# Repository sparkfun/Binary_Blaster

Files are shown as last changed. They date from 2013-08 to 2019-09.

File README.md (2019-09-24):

Binary Blaster Kit
==============

Binary Blaster (https://www.sparkfun.com/products/12037)

[Binary Blaster (KIT-12037)](https://www.sparkfun.com/products/12037)

This beginner's thru-hole soldering kit is a fun way to learn binary conversion. It displays a decimal value, 
and you are challenged to press the buttons to represent the correct binary version. Correctly press all 15 
values and you win!

Repository Contents
-------------------

* **/Firmware** - Firmware that comes programmed on the kit.
* **/Hardware** - All Eagle design files (.brd, .sch)

Documentation
-------------------
* [Assembly Guide](https://learn.sparkfun.com/tutorials/binary-blaster-assembly-guide)

License Information
-------------------
The hardware is released under [Creative Commons ShareAlike 4.0 International](https://creativecommons.org/licenses/by-sa/4.0/).
The code is beerware; if you see me (or any other SparkFun employee) at the local, and you've found our code helpful, please buy us a round!

Distributed as-is; no warranty is given.

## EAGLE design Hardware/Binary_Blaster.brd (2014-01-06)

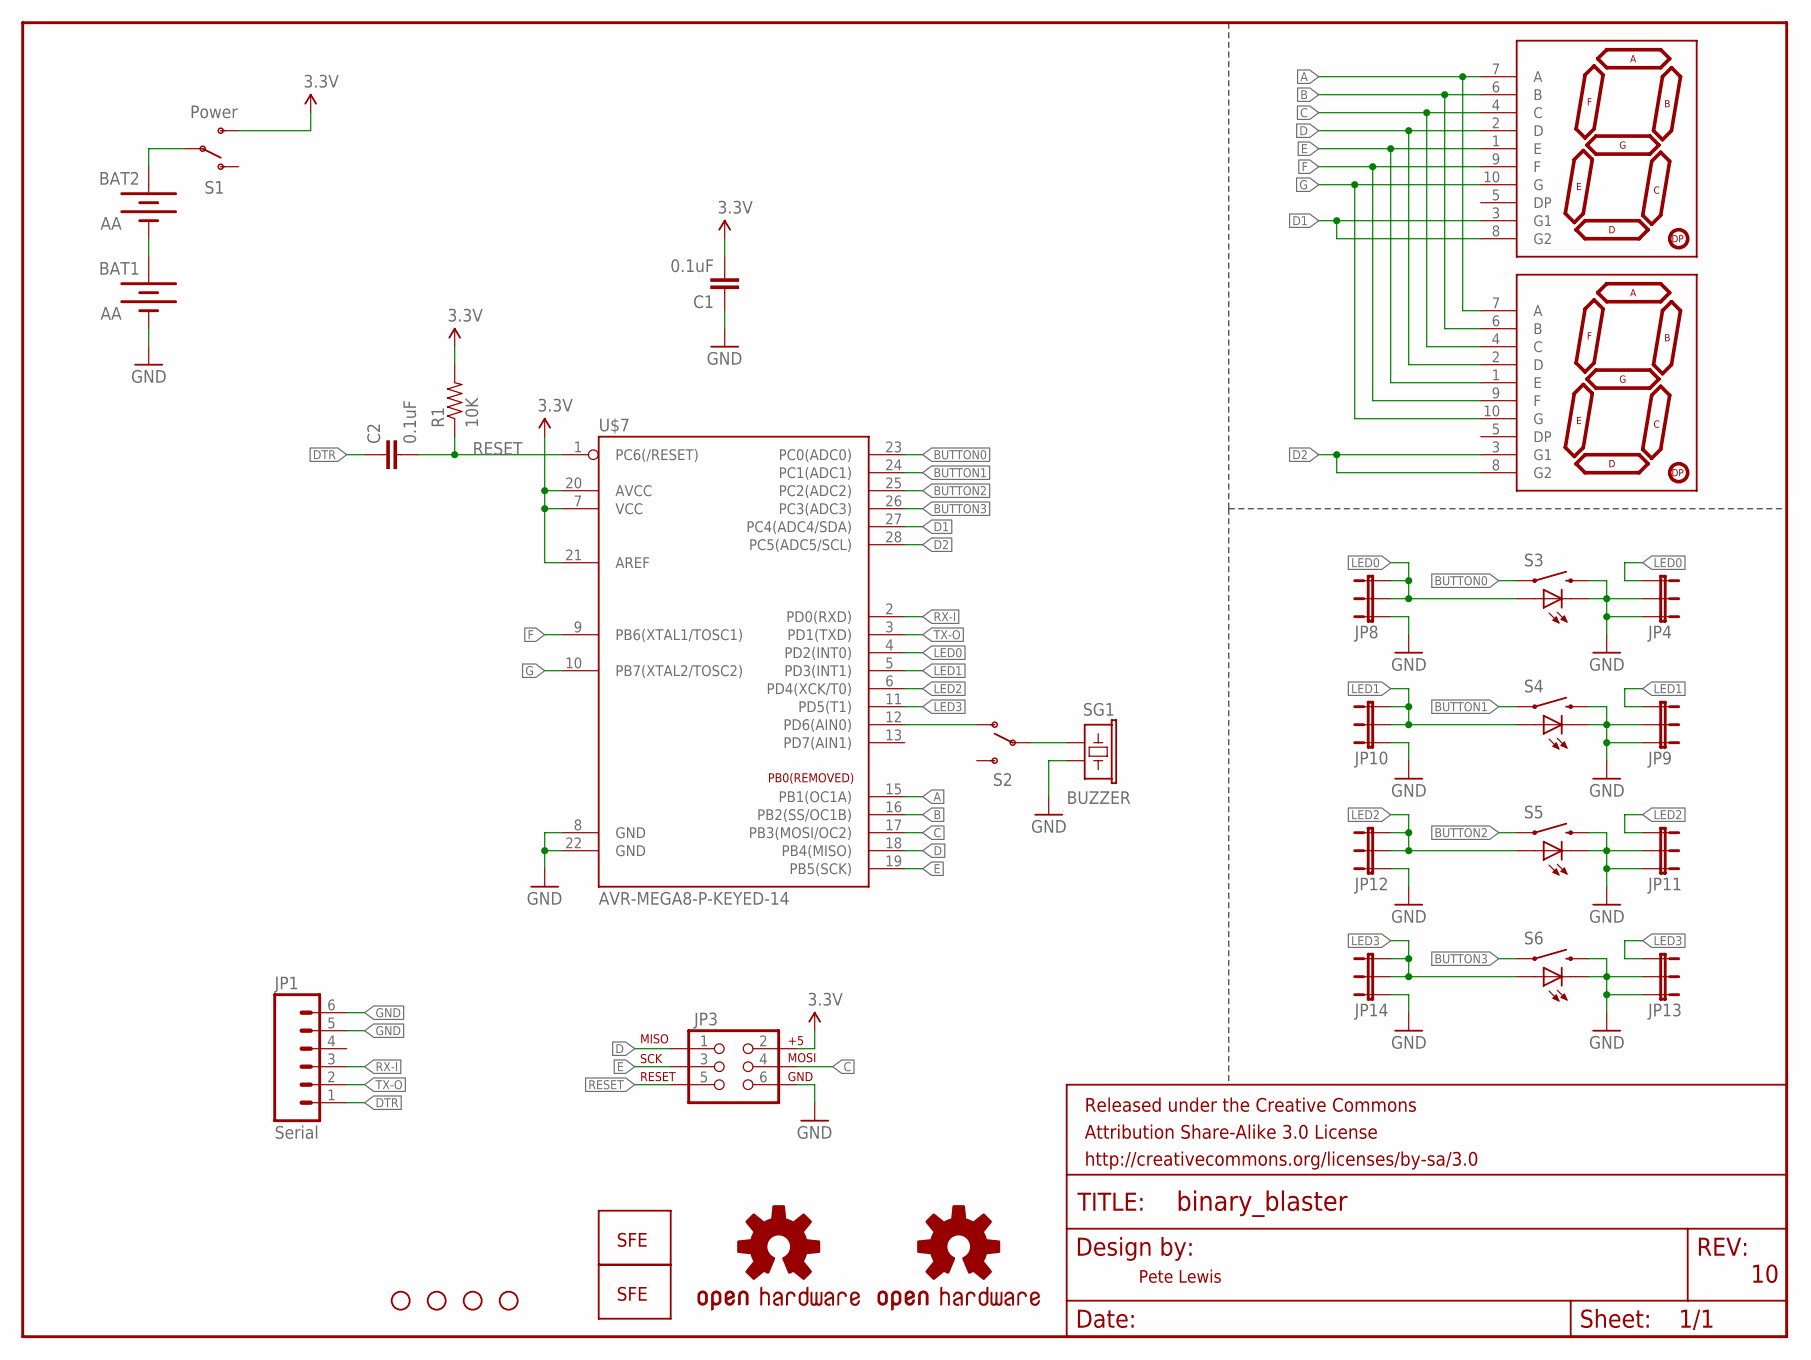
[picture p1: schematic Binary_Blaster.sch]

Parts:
BAT1, BAT2: AA; BATTERY-AA-KIT
C1, C2: 0.1uF; CAP-PTH-SMALL-KIT
FRAME1: FRAME-LETTER; CREATIVE_COMMONS
JP1: Serial; 1X06-NOSILK
JP2, JP5, JP6, JP7: STAND-OFF
JP3: AVR_SPI_PRG_6NS; 2X3-NS
JP4, JP8, JP9, JP10, JP11, JP12, JP13, JP14: JUMPER-3SMD; SJ_3
LOGO1, LOGO2: LOGO-SFENEW; SFE-NEW-WEBLOGO
R1: 10K; AXIAL-0.3-KIT
S1: Power; SWITCH-SPDT_KIT
S2: SWITCH-SPDTKIT; SWITCH-SPDT_KIT
S3, S4, S5, S6: SWITCH-MOMENTARY-LEDEZ; TACTILE-PTH-LED-12MM-EZ
SG1: BUZZER; BUZZER-12MM-KIT
U$1, U$6: 7-SEGMENT-DISPLAY-1"-REDEZ; 7-SEGMENT-1"PTH-EZ
U$2: OSHW-LOGOL; OSHW-LOGO-L
U$3: OSHW-LOGOS; OSHW-LOGO-S
U$7: AVR-MEGA8-P-KEYED-14; DIL28-3_KEYED-14

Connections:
3.3V: C1.2, JP3.2, R1.P$2 (2), S1.3 (S), U$7.7 (VCC), U$7.20 (AVCC), U$7.21 (AREF)
A: U$1.7 (A), U$6.7 (A), U$7.15 (PB1(OC1A))
B: U$1.6 (B), U$6.6 (B), U$7.16 (PB2(SS/OC1B))
BUTTON0: S3.4 (1), U$7.23 (PC0(ADC0))
BUTTON1: S4.4 (1), U$7.24 (PC1(ADC1))
BUTTON2: S5.4 (1), U$7.25 (PC2(ADC2))
BUTTON3: S6.4 (1), U$7.26 (PC3(ADC3))
C: JP3.4, U$1.4 (C), U$6.4 (C), U$7.17 (PB3(MOSI/OC2))
D: JP3.1, U$1.2 (D), U$6.2 (D), U$7.18 (PB4(MISO))
D1: U$1.3 (G1), U$1.8 (G2), U$7.27 (PC4(ADC4/SDA))
D2: U$6.3 (G1), U$6.8 (G2), U$7.28 (PC5(ADC5/SCL))
DTR: C2.1, JP1.1
E: JP3.3, U$1.1 (E), U$6.1 (E), U$7.19 (PB5(SCK))
F: U$1.9 (F), U$6.9 (F), U$7.9 (PB6(XTAL1/TOSC1))
G: U$1.10 (G), U$6.10 (G), U$7.10 (PB7(XTAL2/TOSC2))
GND: BAT1.GND@1 (-), C1.1, JP1.5, JP1.6, JP3.6, JP4.2, JP4.3, JP8.1, JP9.2, JP9.3, JP10.1, JP11.2, JP11.3, JP12.1, JP13.2, JP13.3, JP14.1, S3.2, S3.C, S4.2, S4.C, S5.2, S5.C, S6.2, S6.C, SG1.- (2), U$7.8 (GND), U$7.22 (GND)
LED0: JP4.1, JP8.2, JP8.3, S3.A, U$7.4 (PD2(INT0))
LED1: JP9.1, JP10.2, JP10.3, S4.A, U$7.5 (PD3(INT1))
LED2: JP11.1, JP12.2, JP12.3, S5.A, U$7.6 (PD4(XCK/T0))
LED3: JP13.1, JP14.2, JP14.3, S6.A, U$7.11 (PD5(T1))
unnamed: S2.2, SG1.+ (1)
unnamed: BAT2.PWR@1 (+), S1.2
unnamed: S2.1 (O), U$7.12 (PD6(AIN0))
unnamed: BAT1.PWR@1 (+), BAT2.GND@1 (-)
RESET: C2.2, JP3.5, R1.P$1 (1), U$7.1 (PC6(/RESET))
RX-I: JP1.3, U$7.2 (PD0(RXD))
TX-O: JP1.2, U$7.3 (PD1(TXD))

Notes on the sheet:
Pete Lewis

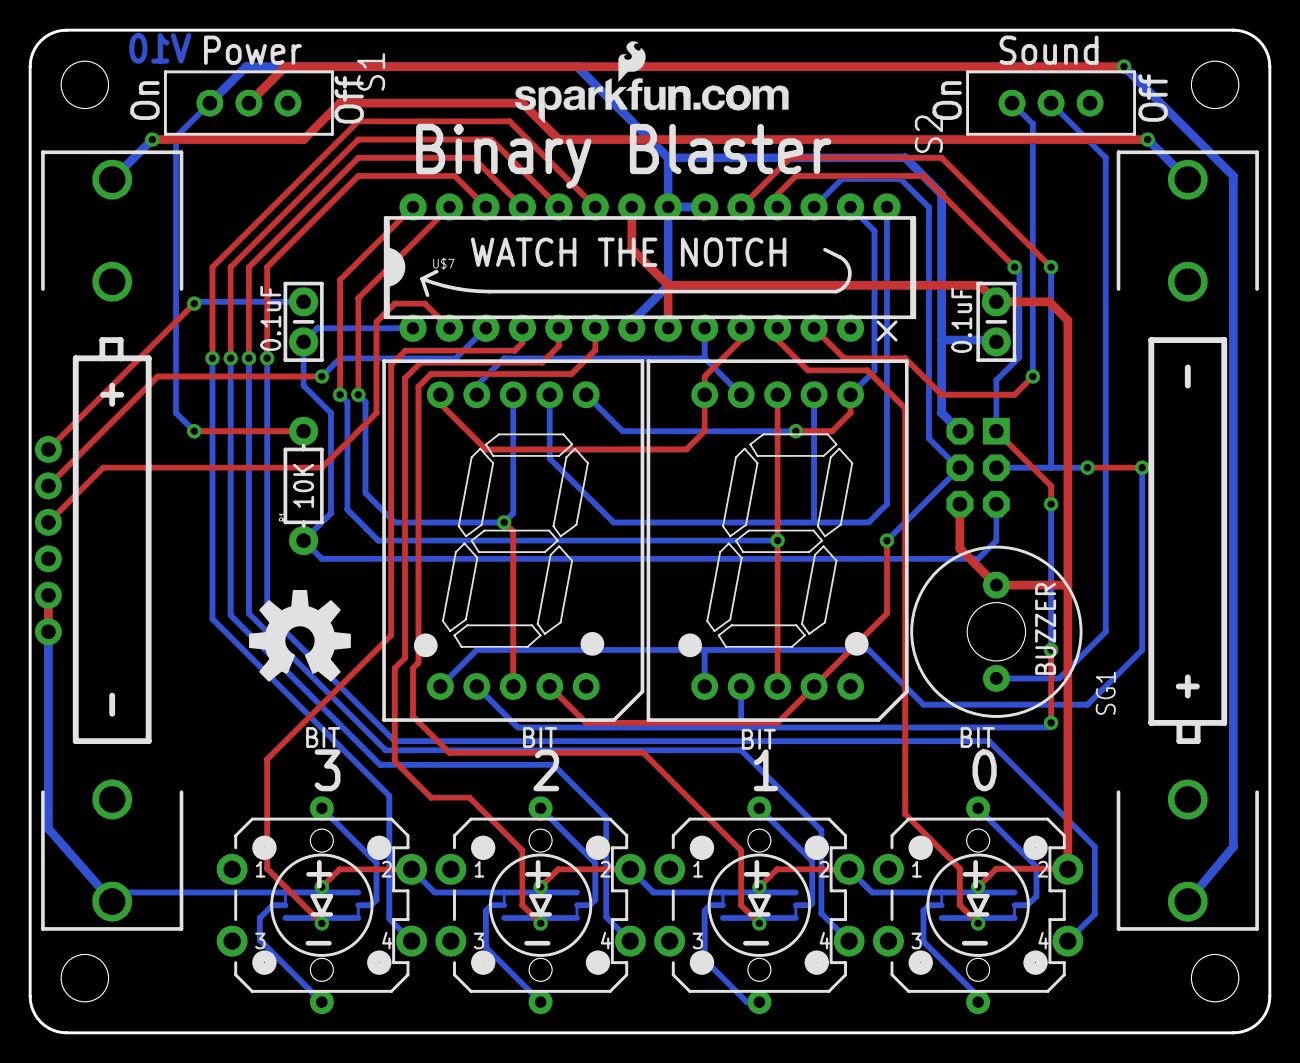
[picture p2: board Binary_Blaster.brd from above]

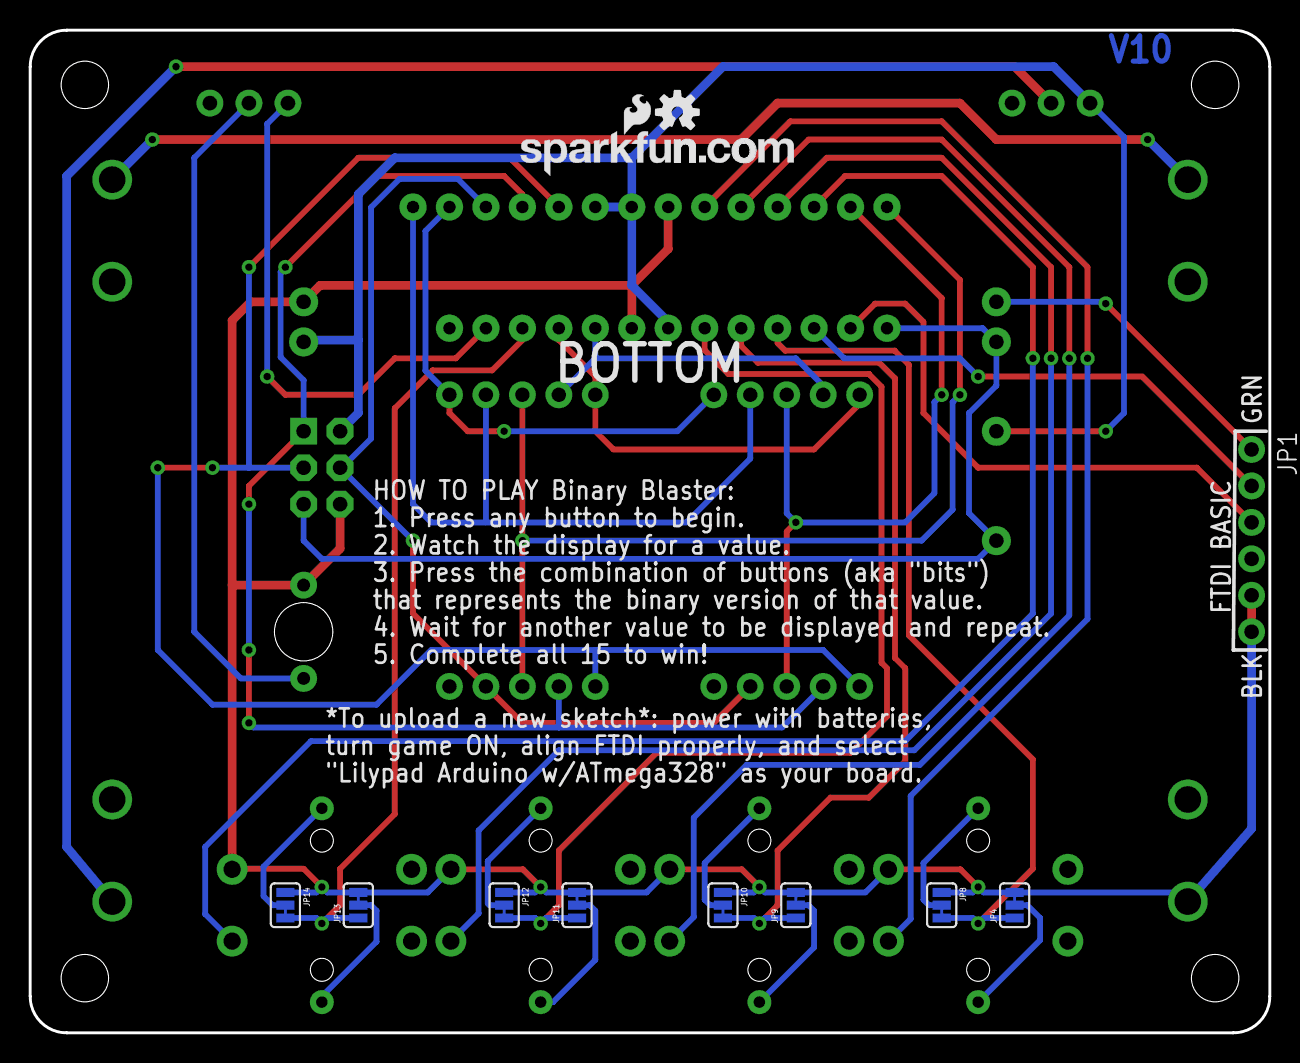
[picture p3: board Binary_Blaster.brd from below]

Board: 2 copper layers, 86.4 x 69.8 mm, 34 parts (12 on the bottom side), 27 nets.

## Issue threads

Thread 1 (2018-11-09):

PCB does not show polarity of buzzer

ursminor, 2018-11-09:

bboyho, 2019-09-24:
Hi,

Thank you for the feedback. I just saw your issue. The buzzer has a polarity marker but it should not matter when soldered on the board. The buzzer will still function regardless of the orientation. Checking with the engineer, we do not believe that this is a significant issue to warrant a revision. If you would like to follow along with the [assembly guide](https://learn.sparkfun.com/tutorials/binary-blaster-assembly-guide#buzzer-and-switches) feel free to insert the buzzer into the PCB by having the "+" close to the "BIT 0" silkscreen as indicated in the image.

If you happen to solder the buzzer differently but wanted to follow the guide, you can rework the board by heating both through holes with your soldering iron and carefully remove the component from the through hole. Using a solder sucker or the [slap method](https://www.sparkfun.com/tutorials/339), remove any remaining solder on the PTH pads. After removing any excess solder from the pins, insert buzzer back into through holes with the orientation based on the guide before soldering the pins again. When reworking PTH components, there is a risk of pulling pads so make sure to fully heat the solder joints!

Closed 2019-09-24.

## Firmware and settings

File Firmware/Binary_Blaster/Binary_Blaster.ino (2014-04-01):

/******************************************************************************
Binary_Blaster.ino
Firmware for the Binary Blaster PTH Soldering Kit
Pete Lewis @ SparkFun Electronics
February 13th 2014
https://github.com/sparkfun/Binary_Blaster

This code is meant to be used with SFE's Binary Blaster thru-hole soldering kit. 
It can be found here: https://www.sparkfun.com/products/12037
It is an educational kit that is meant to teach thru-hole soldering, 
and also challenge the player to practice binary conversion. The default playing
mode is to display the values in decimal. If you'd like to play hexadecimal 
mode, then you can do so by holding down the "bit0" button while powering up.

Resources:
No additional library requirements

Development environment specifics:
Arduino 1.0.5
Hardware: v10*
*Note, PB0 (aka arduino pin "D8") has been removed from the IC, to make it a
keyed part. This helps beginners avoid incorrect placement of the IC.

This code is beerware; if you see me (or any other SparkFun employee) at the
local, and you've found our code helpful, please buy us a round!

Distributed as-is; no warranty is given.
******************************************************************************/

//-----------------------------------------------------------------------------
// HARDWARE PIN DECLARATIONS

// Define the anode (aka "+" or "high side") pins on the 7-segment displays
  // There are two 7-segment displays on this game.
  // We control each display by both writing the anode digit pin HIGH,
  // and writing the desired single segment cathode pin LOW. Only one segment 
  // may be actually lit at one instance. We blink segments in a fast 
  // sequence, and then it appears to illuminate multiple segments 
  // simultaneously. 
  // ***Note, the cathodes for the 7 segments are all connected
  // to the pins on PORTB. These are controlled by writing directly to the
  // entire port (e. g. "PORTB = ~0b00001100;") in function set_7segment_pins().
const int digit_1_anode = A5;
const int digit_2_anode = A4;

// Define pins connected to the switches inside the tactile LED buttons
  // Note, the tactile buttons have switches and LEDs inside them.
  // These pin definitions are for the switches. They will be set as inputs,
  // and used to know if the player is pressing the button down.
  // Each button corresponds to a bit, and therefore has the "bit0" or
  // "bit1" in it's name. This helps keep the player's input more
  // understandable. This pins are read in the function, read_buttons().
const int button_input_pin_bit0 = A3;
const int button_input_pin_bit1 = A2;
const int button_input_pin_bit2 = A1;
const int button_input_pin_bit3 = A0;

// Define pins connected to the LEDs inside the tactile LED buttons
  // Note, These pin definitions are for the LEDs, not the switches.
  // These are used to control the LEDs. If the user presses the correct
  // binary equivalent, then they will light up to show which bits have been
  // set. Turning an LED on means that bit is set. Turning an LED off means
  // that bit is cleared. When the game is waiting for the player to "blast
  // in" the correct bits, all bits are set as cleared.
  // Each LED corresponds to a bit, and therefore has the "bit0" or
  // "bit1" in it's name.
  // These pins are controlled in functions, display_leds() and
  // display_zoom().
const int led_pin_bit0 = 5;
const int led_pin_bit1 = 4;
const int led_pin_bit2 = 3;
const int led_pin_bit3 = 2;

//-----------------------------------------------------------------------------
// GAMEPLAY VARIABLE DECLARATIONS

// Define an array to store the sequence of values the player must repeat
  // This will include 16 possibilities, although we will not use "0",
  // because "0" is hard for the player to input. All other values will 
  // require the player to set bits (aka press the buttons) to create
  // the correct binary 4 bit equivalent.
  // This array will be filled in each time we call shuffle_sequence()
int sequence[16];

// Define a variable to store a time stamp of when we start each game
  // This will be used to calculate the total time it takes the player
  // to complete all 15 possibilities (this is how they win the game). 
  // Note, there is a timeout feature that will cause the player to loose
  // if they do not input the correct buttons within the timeout time.
  // This also resets the game and will require the player to do all 15 again
  // before they can win.
  // At the end of the game, it will display the total time that it took the
  // player to complete all 15. This is their "score" for that completion.
  // This way, the player can know how fast they were able to convert, 
  // and practice to decrease their total time.
long start_timestamp;

// Define the amount of time it takes to timeout during game-play
  // Each time a new value is displayed on the 7-segment displays, the player
  // only has a set amount of time to press the correct buttons. If they think
  // or wait too long, then the game will timeout and reset. This makes the 
  // game a bit more challenging and requires that the player really know
  // their conversions. By default is is set to 1000 milliseconds 
  // (aka 1 second). You can decrease this number to make it more difficult,
  // or make it longer if you'd like to have more time to practice.
  // This variable is used in function, listen_for_value().
#define TIMEOUT_MILISECONDS 1000

// Define a variable to display in hexadecimal or decimal
  // If this is set to true, then it will display in hex.
  // If false, then it will display in decimal.
  // This is checked in the function, display_7seg(), which ultimately changes
  // the display segments in set_7segment_pins().
  // Default is false, if you hold down bit "0" right after powering on, it 
  // will change to hex mode.
boolean Hex_mode = false;

void setup()
{
  // Begin serial for debug readout. Also used to see more precise timestamps
    // aka the players "score" when they have completed the game.
  Serial.begin(9600);
  
  // Increase our odds of a truly random sequence generator
    // Use an analogRead on a floating ADC pin (A0) to help the random() 
    // function to be more truly random. Without this, it seems that
    // the first random order is always the same.
    // Random function is used in suffle_sequence().
  randomSeed(analogRead(A0));
  
  // Button switches (INPUTS with pullups)
  pinMode(button_input_pin_bit0, INPUT_PULLUP);
  pinMode(button_input_pin_bit1, INPUT_PULLUP);
  pinMode(button_input_pin_bit2, INPUT_PULLUP);
  pinMode(button_input_pin_bit3, INPUT_PULLUP);
  
  // Button LEDs (OUTPUTS and also write them LOW aka "off")
  pinMode(led_pin_bit0, OUTPUT);
  pinMode(led_pin_bit1, OUTPUT);
  pinMode(led_pin_bit2, OUTPUT);
  pinMode(led_pin_bit3, OUTPUT);
  digitalWrite(led_pin_bit0, LOW);
  digitalWrite(led_pin_bit1, LOW);  
  digitalWrite(led_pin_bit2, LOW);
  digitalWrite(led_pin_bit3, LOW);

  // Set the anode pins of each 7 segment display to OUTPUTs
    // This will be used to turn on each display individually.
    // Each of these pins is connected to the anode of all 7 segments
    // for its corresponding display. Right them HIGH to turn them on,
    // Right them LOW to turn them off.
  pinMode(digit_1_anode, OUTPUT); // connected to "+" of digit 1 (left)
  pinMode(digit_2_anode, OUTPUT); // connected to "+" of digit 2 (right)
  
  // Set all of the segments control pins to OUTPUT (set to "1")
    // Pins 1-7 on PORT B are used to control the segments on both displays.
    // I can set all of them to outputs with the following single line of code,
    // by setting the register "DDRB" to the desired binary value.
    // *Note, PB0 (aka arduino pin "D8" has been removed from the IC, to make it a
    // keyed part. This helps beginners avoid incorrect placement of the IC.
  DDRB = 0b11111111;
  
  // Set all of the segments control pins to LOW (set to "0")
    // Pins 1-7 on PORT B are used to control the segments on both displays.
    // I can set all of them to outputs with the following single line of code:
  PORTB = 0b00000000; // all low (turn them all off)
  
  // Check for hex or decimal mode
    // If you power up with no buttons pressed, it will default to "Decimal mode"
    // In decimal, the sequence[] array values will appear on the display as 
    // decimal values like so: 
    // "1","2","3","4","5","6","7","8","9","10","11","12","13","14","15".
    // If you power up with the "bit0" button pressed, then it will play in 
    // "Hex mode". In this mode, the numbers in the sequence[] array will 
    // appear on the display as hex values like so:
    // "1","2","3","4","5","6","7","8","9","A","b","C","d","E","F".
    // It will also display all of the possible hex values in hex_mode_entered()
    // to show that mode has been entered.
  if(digitalRead(button_input_pin_bit0) == LOW) 
  {
    Hex_mode = true;
    hex_mode_entered();
  }
  else Hex_mode = false;
  
  // Test out the button LEDs, displays and buzzer
    // This is helpful when you first power up. It can help you verify that the
    // parts have been placed and soldered properly.
  display_roundabout();  // Blinks the segments of each display a bit.
  display_zoom(); // Blinks the button LEDs 
  buzz_blast(300); // Buzzes the buzzer in a "blast off" sort of sound.
}

// the loop routine runs over and over again forever:
void loop()
{
  // Wait for the player to press any button in order to start a new game
    // Enter a while loop that will remain true until they press a button
    // display_counting_waiting() will return true, until a button is pressed.
    // When a button is pressed, it will return false. This will cause the 
    // while loop to no longer be true, and thus allow us to continue on to 
    // the start of the game (the rest of the main loop)
  while(display_counting_waiting());
  
  // Shuffle the order of the values in the sequence[] array.
    // This makes the game more challenging, because each time the player starts
    // a new game, they will get the 15 possibilities in a different order.
  shuffle_sequence();
  
  // Display a blinks on the button LEDs to indicate the new game start.
  display_zoom();
  
  // Take a time stamp to remember when they started the active game.
    // This will be used later to calculate their total time (aka "score")
  start_timestamp = micros();
  
  // Show the time stamp in a serial terminal window. Mostly for debugging.
  Serial.print("start_timestamp:");
  Serial.println(start_timestamp);
  
  // Show the player each value in the sequence[] array (one at a time).
    // Use a "for" loop to show each value, and listen to player input
    // As they correctly input each value, increment to the next spot in 
    // the sequence[] array.
  for(int i = 0 ; i < 16 ; i++)
  {
    // Check to see if the player has made it to the last spot in the sequence[]
      // array - which is 15. If they have, then call the function,
      // display_winner() and break out of this for loop.
    if(i == 15)
    {
      display_winner(); // player made it through all 15 - they win!
      break;
    }
    
    // Display a roundabout blink on the display, to give the player a small
      // amount of time to get ready for the next value to appear.
    display_roundabout();
    
    // Display the current value that the player must input.
      // We use the index in this for loop, "i", to call from the 
      // sequence[] array
    display_7seg(sequence[i]);
    
    // Wait for the player to input the correct value.
      // Note, most of this is done in the function, listen_for_value().
      // Check that out in the lower portion of this code for more info.
      // We are waiting for the correct value. If the player inputs the correct
      // value, then listen_for_value() will return true, and the following if
      // statement contents will execute. If they timeout, then 
      // listen_for_value() will return false, and we will continue on to 
      // show loser and break out of this for loop.
    if(listen_for_value(sequence[i])) 
    {
      // If we get here, it means the player has pressed the correct input
      // Now, let's show the correct value on button LEDs.
      display_leds(read_buttons());
      
      // Buzz a "blast" tone on the buzzer. Use the index "i" to increment
        // the start note higher each time we climb up to 15. This causes the 
        // tone to get higher and higher in pitch each time, adding an element 
        // of excitement and urgency as they get closer to winning.
      int start_note = 300;
      start_note += i*40;
      buzz_blast(start_note);
      
      // Clear all of the button LEDs
      display_leds(0);
    }
    else // If we get here, the player has timed out, and thus lost the game.
    {
      display_loser();
      
      // Show the user what they should have pressed.
      // This is designed to help a beginner learn the conversions, and 
      // hopefully enables a true binary newbie to learn it by simply watching 
      // and repeating.
      display_value(sequence[i], 500);
      
      // Indicate we are resetting.
      display_roundabout();
      break; 
    }  
  }  
}

// Define a function to listen for a value to be pressed on the buttons
  // Send this function a value, and it will return "true" as soon as the 
  // player presses the correct value. If the player does not press the
  // desired value on the buttons, then this function will eventually
  // timeout and return a "false". Also note, the player can actually input
  // any wrong combination of buttons, and it will not do anything.
  // The only way a player can lose, is by timing out.
boolean listen_for_value(int correct_value)
{
  int timeout = TIMEOUT_MILISECONDS;
  while(timeout)
  {
    display_7seg(correct_value);
    
    // Clear button LEDs
    display_leds(0);
    
    // Set button LEDs to whatever the player is currently pressing,
    // even if it is incorrect. This is designed to show the player
    // they must press multiple buttons at the same time, because
    // when they release a button, the led will turn off.
    display_leds(read_buttons());
    
    // Take another reading of the buttons, and if it's correct
    // then return true.
    if(read_buttons() == correct_value)
    {
      return true;
    } 
    timeout -=1;
  }
  return false; // if we get here, the player has timed out
}

// Define a function to set the 7 individual segment pins
  // Send this function a decimal value, and it will set the 7 pins
  // connected to the segments to look like a "1", "2", and so on.
  // *Note, these segment control pins are bussed in the hardware to
  // both displays (aka digits). In order to properly control each display,
  // you must also set the desired anode pin control (digit_1_anode or
  // digit_2_anode).
  // **Note, you can send this function some special decimal values
  // above 100 (see below) to have more precise control. This method is used
  // in the function blink_segment() and display_roundabout() for fun blinking
  // during game-play and while waiting to start a new game.
  // ***Note, if you send it 10-15, it will display in HEX
void set_7segment_pins(int decimal_val)
{
  // The following if statements set the entire port to control all 
    // 7 control pins in one line of code. The letter above each binary
    // value represent each segment, and correspond to the letters defined
    // in the data sheet for the display. See the entire data sheet here:
    // https://www.sparkfun.com/datasheets/Components/YSD-160AR4B-8.pdf
                                //GFEDCBA-
  if(decimal_val == 1) PORTB = ~0b00001100;
  if(decimal_val == 2) PORTB = ~0b10110110;
  if(decimal_val == 3) PORTB = ~0b10011110;
  if(decimal_val == 4) PORTB = ~0b11001100;
  if(decimal_val == 5) PORTB = ~0b11011010;
  if(decimal_val == 6) PORTB = ~0b11111010;
  if(decimal_val == 7) PORTB = ~0b00001110;
  if(decimal_val == 8) PORTB = ~0b11111110;
  if(decimal_val == 9) PORTB = ~0b11011110;
  if(decimal_val == 0) PORTB = ~0b01111110;
  // The next if statements are for displaying HEX values
  if(decimal_val == 10) PORTB = ~0b11101110; // "A"
  if(decimal_val == 11) PORTB = ~0b11111000; // "b"
  if(decimal_val == 12) PORTB = ~0b01110010; // "C"
  if(decimal_val == 13) PORTB = ~0b10111100; // "d"
  if(decimal_val == 14) PORTB = ~0b11110010; // "E"
  if(decimal_val == 15) PORTB = ~0b11100010; // "F"
  // Special decimal values used to light up individual segments
                                  //GFEDCBA-
                                  //7654321-
  if(decimal_val == 101) PORTB = ~0b00000010;
  if(decimal_val == 102) PORTB = ~0b00000100;
  if(decimal_val == 103) PORTB = ~0b00001000; 
  if(decimal_val == 104) PORTB = ~0b00010000; 
  if(decimal_val == 105) PORTB = ~0b00100000; 
  if(decimal_val == 106) PORTB = ~0b01000000; 
  if(decimal_val == 107) PORTB = ~0b10000000;  
}

// Define a function to control both displays (both the left and right digits)
  // Send this function two integers. They will be blinked either 6 or 3 ms.
  // If you don't send a digit 2 value, then it will default to "-1" and this
  // will cause the function to only display a value on digit 1.
  // d1 is the right digit. It is controlled by digit_1_anode.
  // d2 is the left digit. It is controlled by digit_2_anode.
void display_dig1_2(int d1, int d2=-1)
{
  // Define a delay time variable. this helps keep the timing the same, whether
  // you want to display one or two digits.
  // Default to 6 (milliseconds)
  int delay_time = 6; 
  
  // Cut it in half (to 3 milliseconds) if you're displaying 2 digits.
  if(d2 != -1) delay_time = 3;
  
  // Always at least display digit 1
  set_7segment_pins(d1);
  digitalWrite(digit_1_anode, HIGH);
  digitalWrite(digit_2_anode, LOW);
  delay(delay_time);
  
  // Only if there was a non-default value sent, display digit 2
  if(d2 != -1)
  {
    set_7segment_pins(d2);
    digitalWrite(digit_1_anode, LOW);   
    digitalWrite(digit_2_anode, HIGH);  
    delay(delay_time);               
  }
  
  // Turn both digits off
  digitalWrite(digit_1_anode, LOW);  
  digitalWrite(digit_2_anode, LOW);  
}

// Define a function to display any value 1-99 on the two displays
  // Send this function a value from 1- 99, and it will blink (very briefly)
  // the value on the displays. It will use one or two displays as necessary.
  // Note, this is a very quick blink of a value, in order to actually see the 
  // segments light up for a substantial time, you must loop this function.
  // Note, because we can only control each display one-at-a-time, we must
  // separate digit 1 and 2 from any values greater than 9.
  // This function also checks for Hex_mode. To display in hexadecimal, this
  // function can simply send values greater than 9 as a single digit value to
  // display_dig_2(). set_7segment_pins() will take care of the rest.
void display_7seg(int value)
{
  if((value < 10) | Hex_mode) display_dig1_2(value);
  else 
  {
    // Define two separate variables to store digit 1 and digit 2.
    int dig1 = 0;
    int dig2 = value;
    
    // Continue to subtract 10 from the original value, until you reach below 10.
    // Each time we subtract 10, increment digit 1.
    while(dig2 >= 10) 
    {
      dig2 -= 10;
      dig1 += 1;
    }
    
    // Send our refined digit values to display_dig1_2() function.
    display_dig1_2(dig2, dig1); 
  }
}

// Define a function to randomly shuffle the 15 options in the sequence[] array
  // This function will take the sequence[] array and then randomize the order.
  // It's a bit more tricky then I first thought, so I'll try to break it down
  // as best I can. The key to this function working properly is the scooting
  // that happens at the second for loop. It enables us to keep track of the 
  // remaining available options, and ultimately avoids any doubling of options
  // in the final shuffled array.
void shuffle_sequence()
{
  // Start with all 15 options available
  int sequence_options[16] = {1,2,3,4,5,6,7,8,9,10,11,12,13,14,15};
  
  // Using a for loop, choose a random position (aka value) from 
  // sequence_options[] array
  for(int i = 0 ; i < 15 ; i++)
  {
    // Create a random number between 0 and "15-i".
    // The "15-i" is the tricky part of this shuffle function. It is necessary
    // because we are going to scoot the remaining options to the left each time
    // we pull a new random value from sequence_options[] array.
    int random_choice = random(0,15-i);
    
    // Set the current sequence spot (call with our index, "i", to a randomly 
    // chosen option
    sequence[i] = sequence_options[random_choice]; 
  
    // Scoot the remaining options over to the left
    // This is so we can pick from the beginning of the array next time we loop
    // around in this for loop.
    // Starting at "random_choice" position, move everything else over one spot.
    for(int j = random_choice ; j < 15 ; j++)
    {          
    // Grab the option next door (j+1), and scoot it over one spot (j).
    // Do this until you've reached the end of the array (j will be 14)    
    sequence_options[j] = sequence_options[j+1];   
    }                                                
  }
}

// Define a function to read the four buttons for player input
  // This function will return an integer, "input_var", that the player is
  // currently pressing the binary equivalent on the buttons.
  // It reads each button, and sets the corresponding bit within "input_var".
int read_buttons(){
  int input_var = 0;
  if(!digitalRead(button_input_pin_bit0)) input_var |= (1<<0);
  if(!digitalRead(button_input_pin_bit1)) input_var |= (1<<1);
  if(!digitalRead(button_input_pin_bit2)) input_var |= (1<<2);
  if(!digitalRead(button_input_pin_bit3)) input_var |= (1<<3);
  return input_var;
}
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

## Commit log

2013-08-19 initial eagle files
    [Binary_Blaster_v01.brd, Binary_Blaster_v01.sch]
2013-08-20 replaced devices with Prod_ID versions
    Also included gitignore and removed version number from board/sch file
    names.
    [Binary_Blaster.brd, Binary_Blaster.sch, Binary_Blaster_v01.sch]
2013-10-10 Firmware and "v02" of hardware
    v02: changed to "EZ" packages on display and leds, corrected silk on led
    package. Moved to larger display (the we carry in house).
    [Binary_Blaster.brd, Binary_Blaster.sch]
2013-10-24 ignoring gerbers, drill files, and zipped gerbers
2013-10-24 hardware v03
    Fixed bottom silk so it no longer overlaps with pads. Also added 4 tips
    for uploading a sketch.
    [Binary_Blaster.brd]
2013-10-29 Fixed display function for numbers above 15
    The display function was not separating the 1st and 2nd digit properly
    for displaying on the 7 segments. It was always displaying "22", "33",
    "44", or "55". Now it can show you your score properly. Also added new
    variable for total score kept in "total_time_microseconds". It will
    display this more precise score on serial debug at 9600.
    [Binary_Blaster.ino]
2013-10-30 Added batch file fore file cleanup
    Deletes board and schematic backup files, and most common files created
    during CAM job. Also deletes zip files (where usually put cammed up
    gerbers)
2013-10-30 Updated 7-segment display to include more silk
    [Binary_Blaster.brd, Binary_Blaster.sch]
2013-10-30 cleaned up part values on buttons
    [Binary_Blaster.brd, Binary_Blaster.sch]
2013-10-30 Added LED polarity swap trick
    Still V03
    [Binary_Blaster.brd, Binary_Blaster.sch]
2013-12-06 created display_roundabout_waiting()
    This helped improve response time to a button press while in waiting
    mode. It now checks for a button press after each segment lights up in
    the roundabout.
2014-01-06 V10
    -changed bottom copper version to "v10"
    -added "pete lewis" to designed by on board tname layer
    -changed version to "10" on schematic
    [Binary_Blaster.brd, Binary_Blaster.sch]
2014-02-21 added display_counting_waiting() and changed LED reaction during gameplay
    Now the waiting mode is showing the correct values and button combos
    from 1-5. You can still hit a button to start a new game at any time.
    Also, made it so the LEDs react to your pressing during the timeout
    while loop. This is in an effort to show the player that they must hold
    down the combo of buttons at the same time. It kind of shows that the
    buttons don't change permanently because they only stay lit when you
    press them.
    [Binary_Blaster.ino]
2014-04-01 Added randomSeed to setup, and COMBINED hex file
    A customer, menehune23, commented on the product page about how the
    first time you play after a power cycle the order of the sequence is
    always the same. Adding a randomSeed in the setup (usuing A0 - before it
    is setup with it's internal pullup) solved the issue. Now it is much
    more random, and I doubt it will ever start with the same exact
    sequence.
    Also added the combined hex file that we are programming with in
    production. This has been requested on other kits, so I thought I'd
    throw it in this repo too.
    [Binary_Blaster.ino]

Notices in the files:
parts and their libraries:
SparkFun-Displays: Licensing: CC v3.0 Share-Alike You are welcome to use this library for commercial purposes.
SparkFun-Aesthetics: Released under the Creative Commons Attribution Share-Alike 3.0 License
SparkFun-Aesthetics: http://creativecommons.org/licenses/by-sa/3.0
